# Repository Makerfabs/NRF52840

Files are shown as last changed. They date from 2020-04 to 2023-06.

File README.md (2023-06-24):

# MakePython nRF52840

```c++
/*
Version:		V2.0
Author:			UNKOWN
Create Date:	UNKOWN
Note:
	2020/7/24	v2.0: Rebuid readme,add pic. By Vincent
*/
```

[toc]

# Introduce

Python is one of the most widely used, simple and easy-to-learn programming languages around. CircuitPython is a lean implementation of the Python 3 programming language that has been pared down to run efficiently on microcontrollers.
MakePython nRF52840 is a powerful, generic BLE MCU module target to CircuitPython/MicroPython learners & developers. It is true “breadboard compatible”, with the very detailed pins explanation, it is easy to learn& use. The nRF52840 is ready to take advantage of the considerable performance improvements for Bluetooth Low Energy (LE) with the arrival of the Bluetooth 5 specification. Of greatest importance is the support for longer range (up to x4 compared to Bluetooth 4.x) and doubling of on-air data rate, up to 2 Mbs from 1 Mbs in Bluetooth 4.x
The MakePython nRF52840 leads out all pins of Nordic nRF52840, is programmed with CircuitPython by default, users can begin the CircuitPython developing as getting then on hand. It is also compatible with the Arduino making it easy to get started if the correct bootloader downloaded. There also the Makerfabs MakePython ESP8266, MakePython ESP32 and so on.

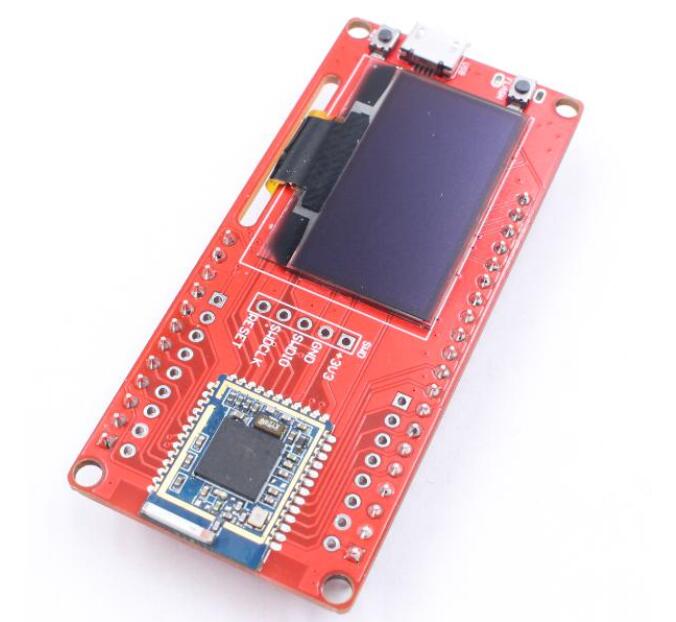
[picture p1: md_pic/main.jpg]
main


- You can get one from: [MakePython_nRF52840](https://www.makerfabs.com/makepython-nrf52840.html)

- Hardware and detailed instructions please visit Wiki page: [MakePython_nRF52840 Wiki](https://wiki.makerfabs.com/MaESP_nRF52840.html)

# Related Test

Visit the wiki for details.

- Display animation



- bluetooth communication



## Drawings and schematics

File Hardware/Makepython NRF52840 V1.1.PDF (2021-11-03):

# P0.06 P⁰.07

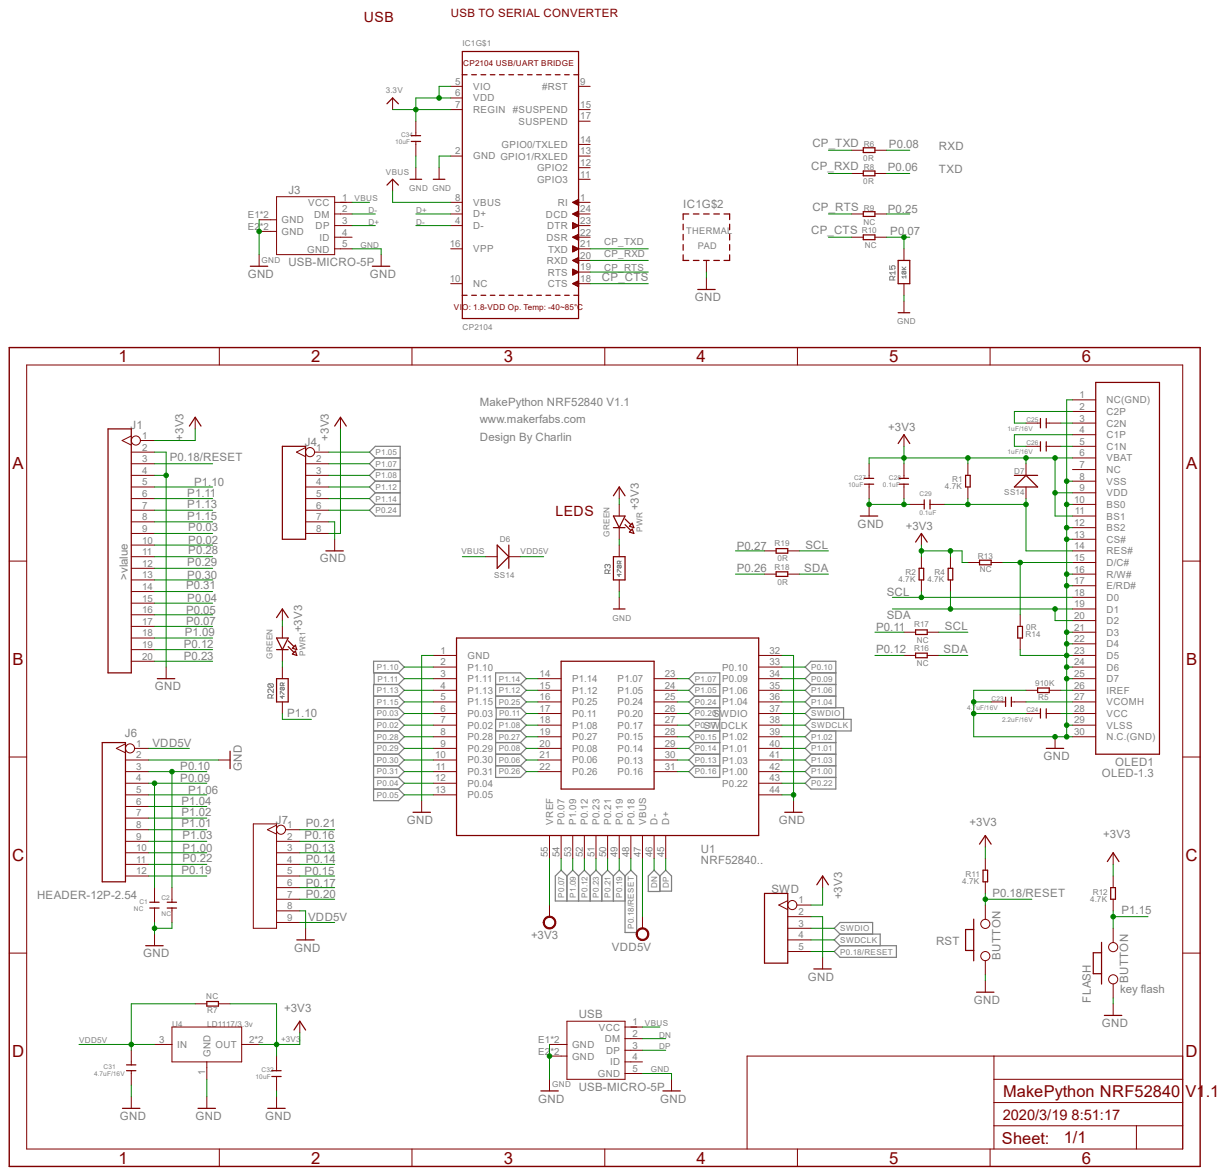
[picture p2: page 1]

VIO: 1.8-VDD Op. Temp: -40~85°C

NC 7 VSS 8 VDD 9

D1 19
D2 20

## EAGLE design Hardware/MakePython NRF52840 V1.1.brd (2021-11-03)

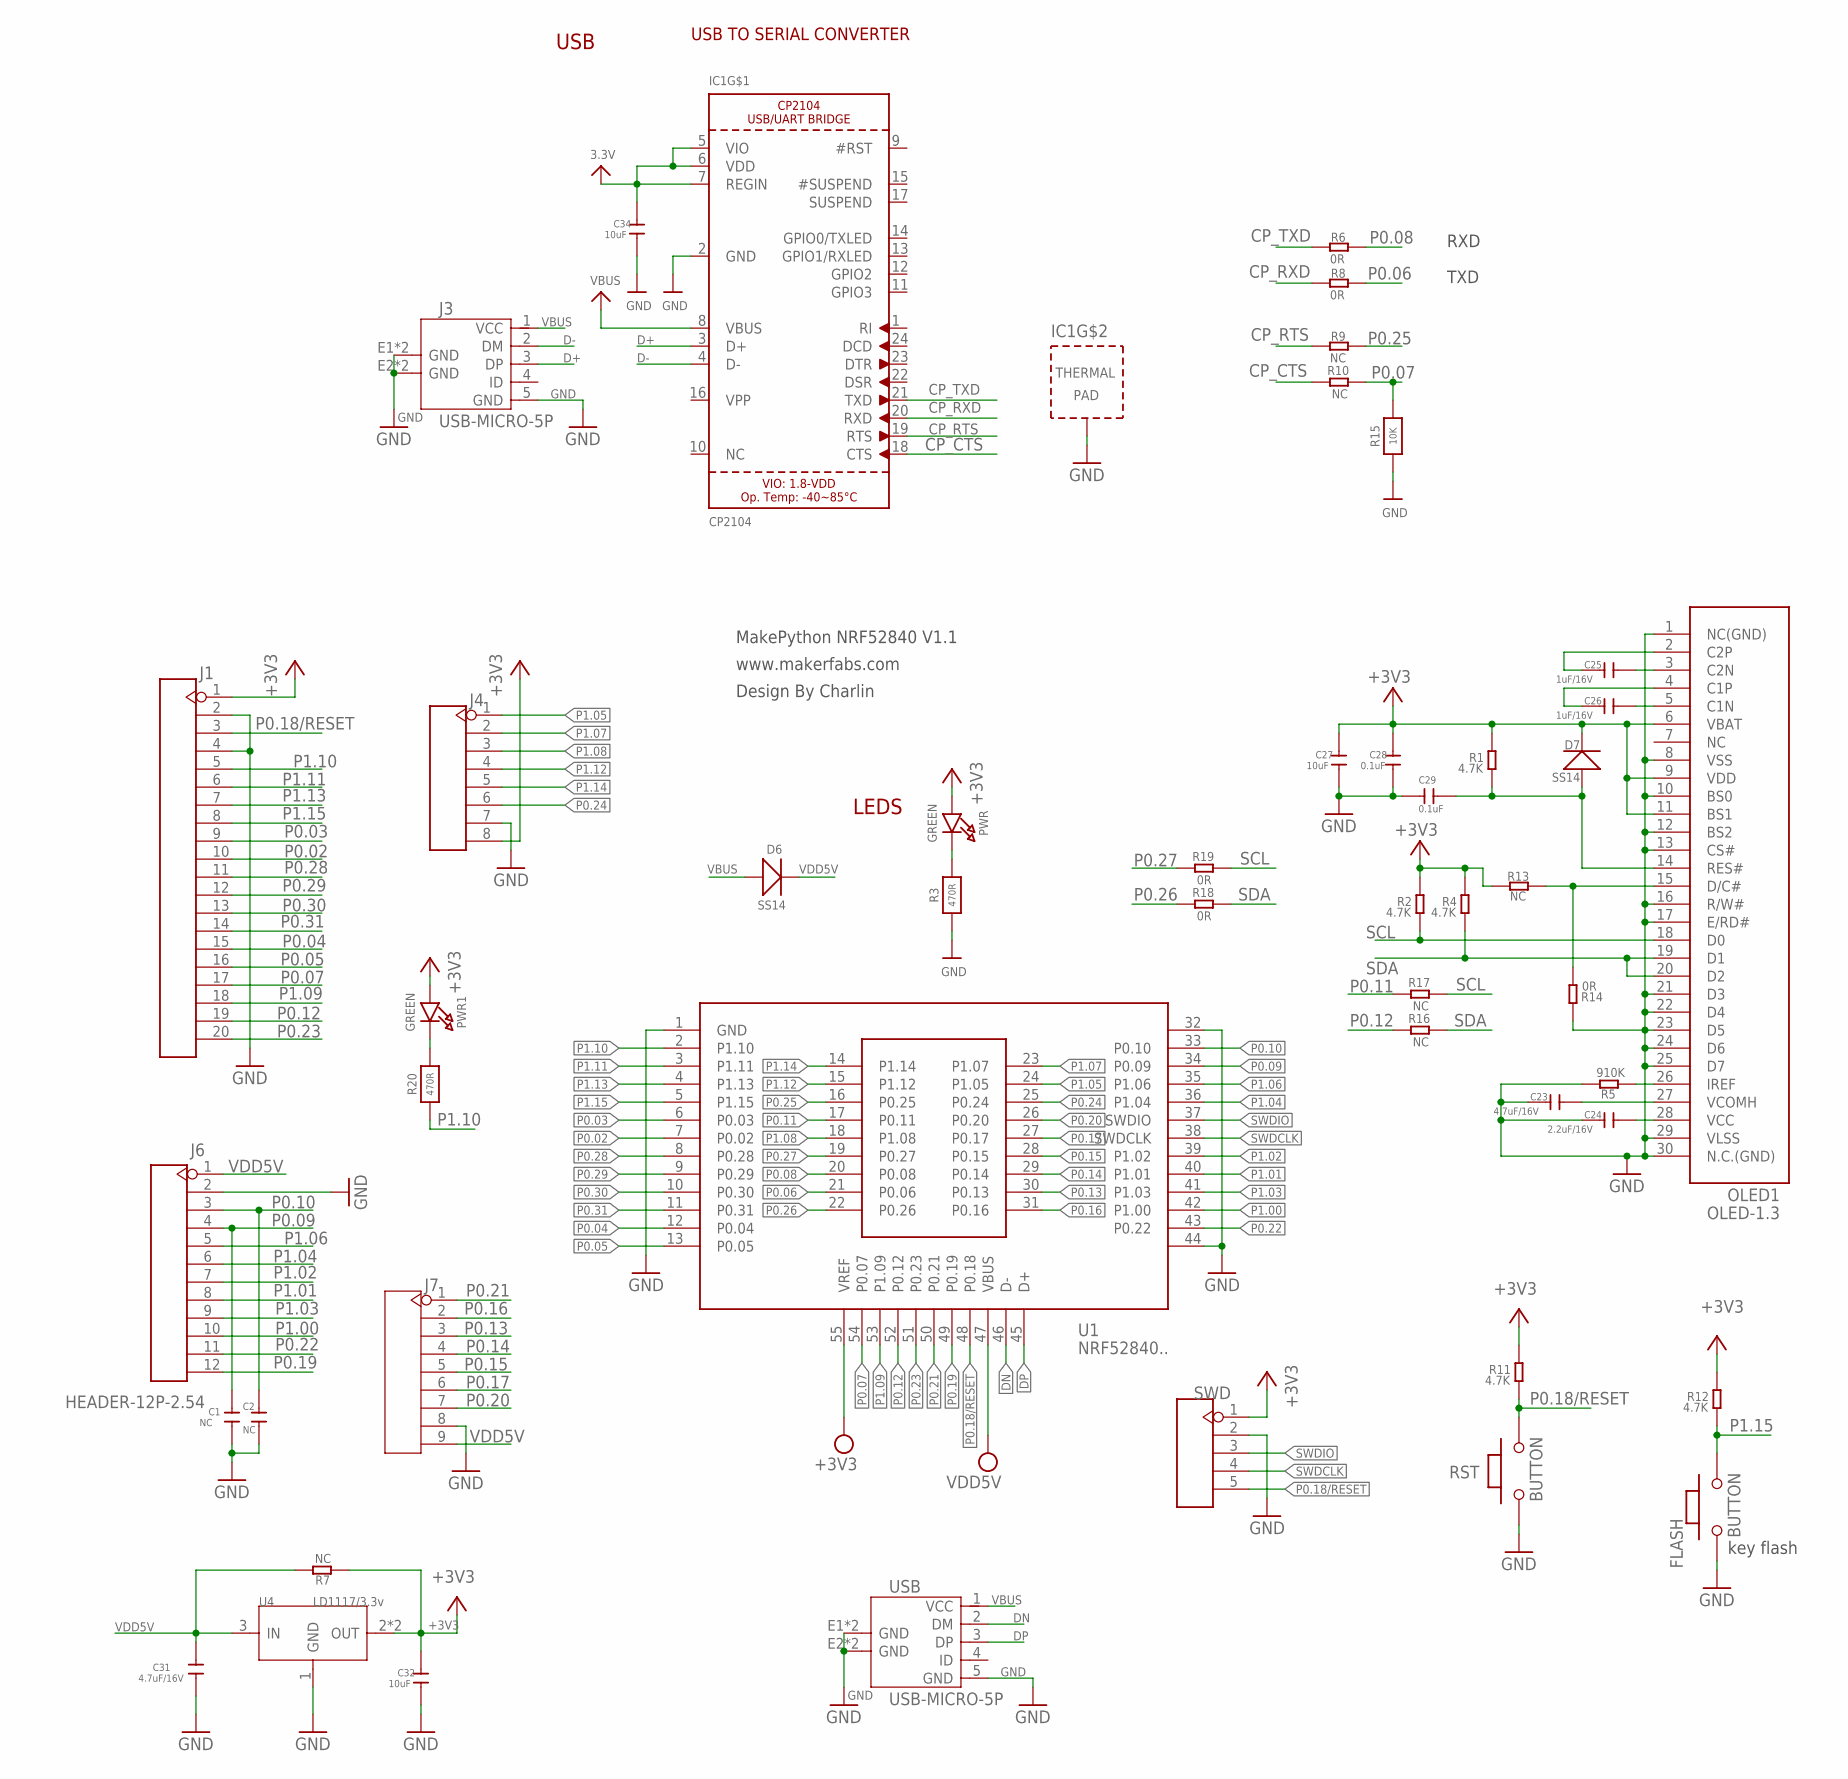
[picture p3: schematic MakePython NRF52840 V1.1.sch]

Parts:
C1, C2: NC; C0603
C23, C31: 4.7uF/16V; C0603
C24: 2.2uF/16V; C0603
C25, C26: 1uF/16V; C0603
C27, C32, C34: 10uF; C0603
C28, C29: 0.1uF; C0603
D6, D7: SS14; SOD323
FLASH: BUTTON; 157SW
IC1: CP2104; QFN24_4MM_SMSC
J1: HEADER-20P-2.54; 20P-2.54
J3: USB-MICRO-5P; MICRO-USB-5P
J4: HEADER-8P-2.54; 8P-2.54
J6: HEADER-12P-2.54; 12P-2.54
J7: HEADER-9P-2.54; 9P-2.54
OLED1: OLED-1.3
PWR, PWR1: GREEN; CHIPLED_0805_NOOUTLINE
R1, R2, R4, R11, R12: 4.7K; 0603
R3, R20: 470R; 0603-NO
R5: 910K; 0603
R6, R8, R14, R18, R19: 0R; 0603
R7, R9, R10, R13, R16, R17: NC; 0603
R15: 10K; 0603-NO
RST: BUTTON; 157SW
SWD: HEADER-5P-2.54; 5P-2.54
U1: NRF52840..
U4: LD1117/3.3v; SOT89
USB: USB-MICRO-5P; MICRO-USB-5P

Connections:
+3V3: C27.1, C28.1, C32.1, C34.1, D7.-, IC1.5 (VIO), IC1.6 (VDD), IC1.7 (REGIN), J1.1, J4.8, OLED1.6 (VBAT), OLED1.9 (VDD), OLED1.11 (BS1), PWR.A, PWR1.A, R1.2, R2.2, R4.2, R7.2, R11.2, R12.2, R13.2, SWD.1, U1.55 (VREF), U4.2 (OUT), U4.4 (OUT)
CP_CTS: IC1.18 (CTS), R10.2
CP_RTS: IC1.19 (RTS), R9.2
CP_RXD: IC1.20 (RXD), R8.2
CP_TXD: IC1.21 (TXD), R6.2
D+: IC1.3 (D+), J3.3 (DP)
D-: IC1.4 (D-), J3.2 (DM)
DN: U1.46 (D-), USB.2 (DM)
DP: U1.45 (D+), USB.3 (DP)
GND: C1.2, C2.2, C23.2, C24.2, C27.2, C28.2, C29.1, C31.2, C32.2, C34.2, FLASH.1, IC1.2 (GND), IC1.THERM (TP), J1.2, J1.4, J3.5 (GND), J3.E1 (GND), J3.E2 (GND), J3.P1 (GND), J3.P2 (GND), J4.7, J6.2, J7.8, OLED1.1 (NC(GND)), OLED1.8 (VSS), OLED1.10 (BS0), OLED1.12 (BS2), OLED1.13 (CS#), OLED1.16 (R/W#), OLED1.17 (E/RD#), OLED1.21 (D3), OLED1.22 (D4), OLED1.23 (D5), OLED1.24 (D6), OLED1.25 (D7), OLED1.29 (VLSS), OLED1.30 (N.C.(GND)), R3.1, R5.2, R14.2, R15.1, RST.1, SWD.2, U1.1 (GND), U1.32, U1.44, U4.1 (GND), USB.5 (GND), USB.E1 (GND), USB.E2 (GND), USB.P1 (GND), USB.P2 (GND)
unnamed: PWR1.C, R20.2
unnamed: OLED1.15 (D/C#), R13.1, R14.1
unnamed: PWR.C, R3.2
unnamed: C25.1, OLED1.3 (C2N)
unnamed: C25.2, OLED1.2 (C2P)
unnamed: C26.1, OLED1.5 (C1N)
unnamed: C26.2, OLED1.4 (C1P)
unnamed: C29.2, D7.+, OLED1.14 (RES#), R1.1
unnamed: OLED1.26 (IREF), R5.1
unnamed: C24.1, OLED1.28 (VCC)
unnamed: C23.1, OLED1.27 (VCOMH)
P0.02: J1.10, U1.7 (P0.02)
P0.03: J1.9, U1.6 (P0.03)
P0.04: J1.15, U1.12 (P0.04)
P0.05: J1.16, U1.13 (P0.05)
P0.06: R8.1, U1.21 (P0.06)
P0.07: J1.17, R10.1, R15.2, U1.54 (P0.07)
P0.08: R6.1, U1.20 (P0.08)
P0.09: C1.1, J6.4, U1.34 (P0.09)
P0.10: C2.1, J6.3, U1.33 (P0.10)
P0.11: R17.2, U1.17 (P0.11)
P0.12: J1.19, R16.2, U1.52 (P0.12)
P0.13: J7.3, U1.30 (P0.13)
P0.14: J7.4, U1.29 (P0.14)
P0.15: J7.5, U1.28 (P0.15)
P0.16: J7.2, U1.31 (P0.16)
P0.17: J7.6, U1.27 (P0.17)
P0.18/RESET: J1.3, R11.1, RST.2, SWD.5, U1.48 (P0.18)
P0.19: J6.12, U1.49 (P0.19)
P0.20: J7.7, U1.26 (P0.20)
P0.21: J7.1, U1.50 (P0.21)
P0.22: J6.11, U1.43 (P0.22)
P0.23: J1.20, U1.51 (P0.23)
P0.24: J4.6, U1.25 (P0.24)
P0.25: R9.1, U1.16 (P0.25)
P0.26: R18.2, U1.22 (P0.26)
P0.27: R19.2, U1.19 (P0.27)
P0.28: J1.11, U1.8 (P0.28)
P0.29: J1.12, U1.9 (P0.29)
P0.30: J1.13, U1.10 (P0.30)
P0.31: J1.14, U1.11 (P0.31)
P1.00: J6.10, U1.42 (P1.00)
P1.01: J6.8, U1.40 (P1.01)
P1.02: J6.7, U1.39 (P1.02)
P1.03: J6.9, U1.41 (P1.03)
P1.04: J6.6, U1.36 (P1.04)
P1.05: J4.1, U1.24 (P1.05)
P1.06: J6.5, U1.35 (P1.06)
P1.07: J4.2, U1.23 (P1.07)
P1.08: J4.3, U1.18 (P1.08)
P1.09: J1.18, U1.53 (P1.09)
P1.10: J1.5, R20.1, U1.2 (P1.10)
P1.11: J1.6, U1.3 (P1.11)
P1.12: J4.4, U1.15 (P1.12)
P1.13: J1.7, U1.4 (P1.13)
P1.14: J4.5, U1.14 (P1.14)
P1.15: FLASH.2, J1.8, R12.1, U1.5 (P1.15)
SCL: OLED1.18 (D0), R2.1, R17.1, R19.1
SDA: OLED1.19 (D1), OLED1.20 (D2), R4.1, R16.1, R18.1
SWDCLK: SWD.4, U1.38 (SWDCLK)
SWDIO: SWD.3, U1.37 (SWDIO)
VBUS: D6.+, IC1.8 (VBUS), J3.1 (VCC), USB.1 (VCC)
VDD5V: C31.1, D6.-, J6.1, J7.9, R7.1, U1.47 (VBUS), U4.3 (IN)

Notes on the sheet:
LEDS
key flash
USB
USB TO SERIAL CONVERTER
MakePython NRF52840 V1.1
www.makerfabs.com
Design By Charlin
RXD
TXD

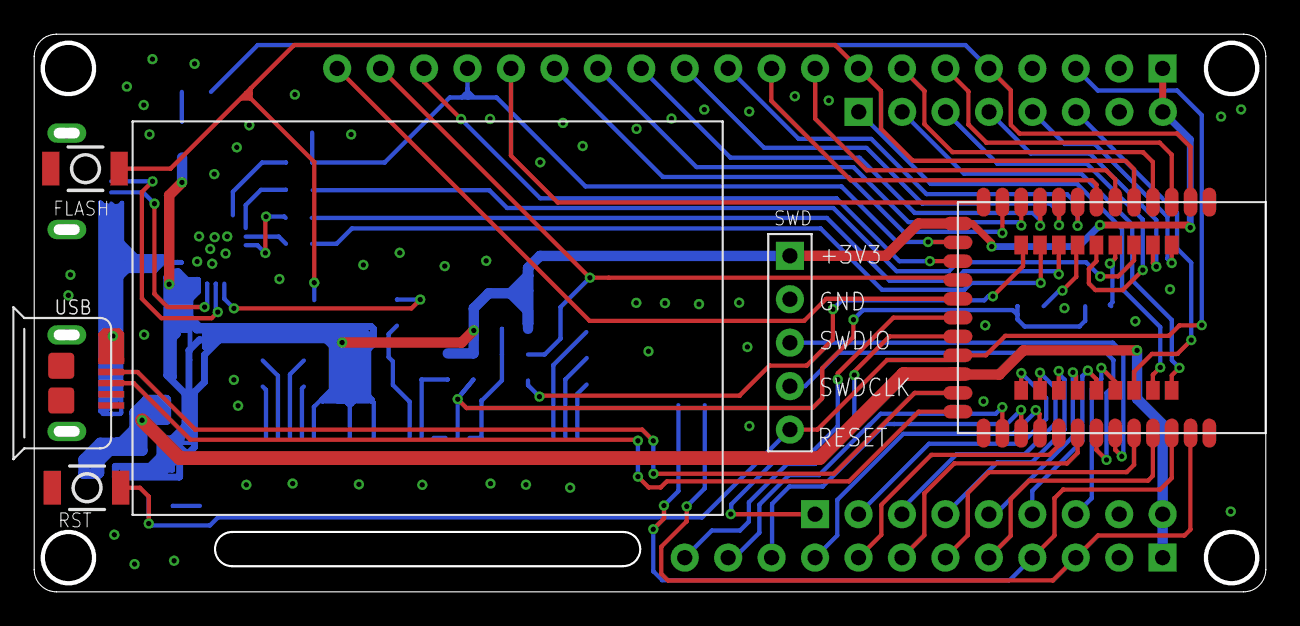
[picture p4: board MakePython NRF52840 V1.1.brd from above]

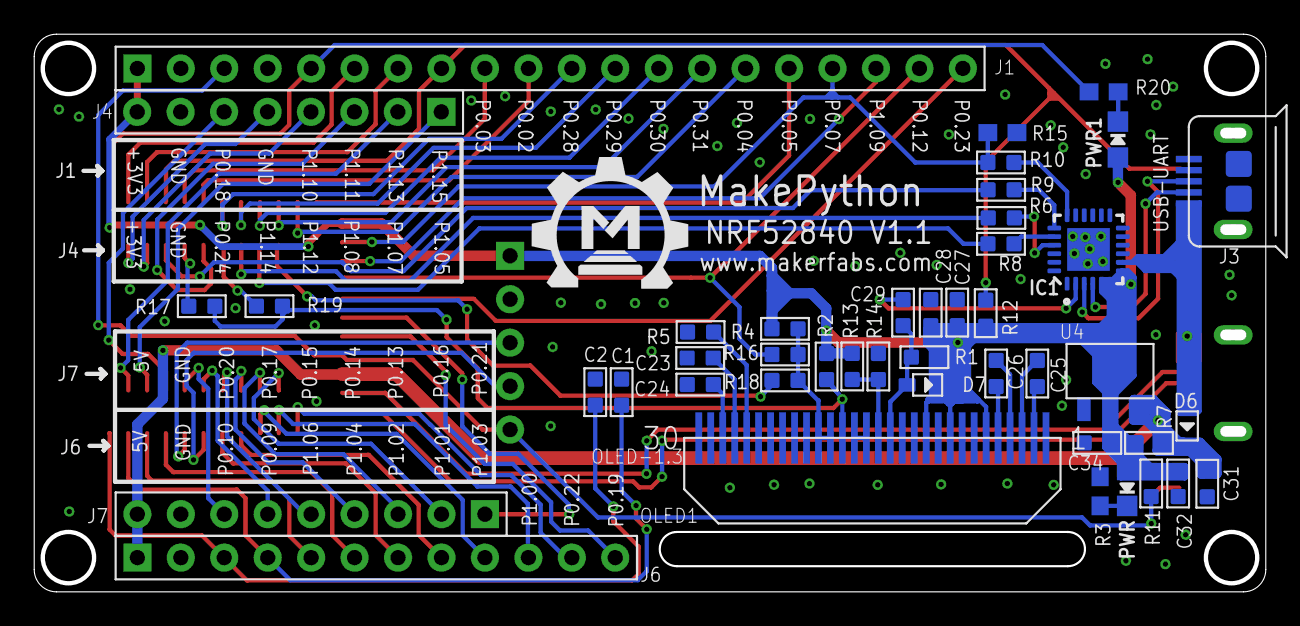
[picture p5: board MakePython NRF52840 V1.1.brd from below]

Board: 2 copper layers, 72.0 x 32.6 mm, 50 parts (44 on the bottom side), 73 nets.

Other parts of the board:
U$1: MAKERFABS_0.3

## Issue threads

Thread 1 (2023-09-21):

LED pin is wrong

bradjc, 2023-09-21:
The "PWR1" LED is connected to pin P1.11.

As far as I can tell the issue is that the nRF52840 module part in the hardware files has pins P1.10 and P1.11 swapped.

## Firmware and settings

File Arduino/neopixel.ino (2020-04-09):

/*********************************************************************
 This is an example for our nRF52 based Bluefruit LE modules

 Pick one up today in the adafruit shop!

 Adafruit invests time and resources providing this open source code,
 please support Adafruit and open-source hardware by purchasing
 products from Adafruit!

 MIT license, check LICENSE for more information
 All text above, and the splash screen below must be included in
 any redistribution
*********************************************************************/

// This sketch is intended to be used with the NeoPixel control
// surface in Adafruit's Bluefruit LE Connect mobile application.
//
// - Compile and flash this sketch to the nRF52 Feather
// - Open the Bluefruit LE Connect app
// - Switch to the NeoPixel utility
// - Click the 'connect' button to establish a connection and
//   send the meta-data about the pixel layout
// - Use the NeoPixel utility to update the pixels on your device

/* NOTE: This sketch required at least version 1.1.0 of Adafruit_Neopixel !!! */

#include <Arduino.h>
#include <Adafruit_NeoPixel.h>
#include <bluefruit.h>

#define NEOPIXEL_VERSION_STRING "Neopixel v2.0"
#define PIN                     30   /* Pin used to drive the NeoPixels */

#define MAXCOMPONENTS  4
uint8_t *pixelBuffer = NULL;
uint8_t width = 0;
uint8_t height = 0;
uint8_t stride;
uint8_t componentsValue;
bool is400Hz;
uint8_t components = 3;     // only 3 and 4 are valid values

Adafruit_NeoPixel neopixel = Adafruit_NeoPixel();

// BLE Service
BLEDfu  bledfu;
BLEDis  bledis;
BLEUart bleuart;

void setup()
{
  Serial.begin(115200);
  while ( !Serial ) delay(10);   // for nrf52840 with native usb

  Serial.println("Adafruit Bluefruit Neopixel Test");
  Serial.println("--------------------------------");

  Serial.println();
  Serial.println("Please connect using the Bluefruit Connect LE application");
  
  // Config Neopixels
  neopixel.begin();

  // Init Bluefruit
  Bluefruit.begin();
  Bluefruit.setTxPower(4);    // Check bluefruit.h for supported values
  Bluefruit.setName("Bluefruit52");
  Bluefruit.Periph.setConnectCallback(connect_callback);

  // To be consistent OTA DFU should be added first if it exists
  bledfu.begin();

  // Configure and Start Device Information Service
  bledis.setManufacturer("Adafruit Industries");
  bledis.setModel("Bluefruit Feather52");
  bledis.begin();  

  // Configure and start BLE UART service
  bleuart.begin();

  // Set up and start advertising
  startAdv();
}

void startAdv(void)
{  
  // Advertising packet
  Bluefruit.Advertising.addFlags(BLE_GAP_ADV_FLAGS_LE_ONLY_GENERAL_DISC_MODE);
  Bluefruit.Advertising.addTxPower();
  
  // Include bleuart 128-bit uuid
  Bluefruit.Advertising.addService(bleuart);

  // Secondary Scan Response packet (optional)
  // Since there is no room for 'Name' in Advertising packet
  Bluefruit.ScanResponse.addName();
  
  /* Start Advertising
   * - Enable auto advertising if disconnected
   * - Interval:  fast mode = 20 ms, slow mode = 152.5 ms
   * - Timeout for fast mode is 30 seconds
   * - Start(timeout) with timeout = 0 will advertise forever (until connected)
   * 
   * For recommended advertising interval
   * https://developer.apple.com/library/content/qa/qa1931/_index.html   
   */
  Bluefruit.Advertising.restartOnDisconnect(true);
  Bluefruit.Advertising.setInterval(32, 244);    // in unit of 0.625 ms
  Bluefruit.Advertising.setFastTimeout(30);      // number of seconds in fast mode
  Bluefruit.Advertising.start(0);                // 0 = Don't stop advertising after n seconds  
}

void connect_callback(uint16_t conn_handle)
{
  // Get the reference to current connection
  BLEConnection* connection = Bluefruit.Connection(conn_handle);

  char central_name[32] = { 0 };
  connection->getPeerName(central_name, sizeof(central_name));

  Serial.print("Connected to ");
  Serial.println(central_name);

  Serial.println("Please select the 'Neopixels' tab, click 'Connect' and have fun");
}

void loop()
{
  // Echo received data
  if ( Bluefruit.connected() && bleuart.notifyEnabled() )
  {
    int command = bleuart.read();

    switch (command) {
      case 'V': {   // Get Version
          commandVersion();
          break;
        }
  
      case 'S': {   // Setup dimensions, components, stride...
          commandSetup();
          break;
       }

      case 'C': {   // Clear with color
          commandClearColor();
          break;
      }

      case 'B': {   // Set Brightness
          commandSetBrightness();
          break;
      }
            
      case 'P': {   // Set Pixel
          commandSetPixel();
          break;
      }
  
      case 'I': {   // Receive new image
          commandImage();
          break;
       }

    }
  }
}

void swapBuffers()
{
  uint8_t *base_addr = pixelBuffer;
  int pixelIndex = 0;
  for (int j = 0; j < height; j++)
  {
    for (int i = 0; i < width; i++) {
      if (components == 3) {
        neopixel.setPixelColor(pixelIndex, neopixel.Color(*base_addr, *(base_addr+1), *(base_addr+2)));
      }
      else {
        neopixel.setPixelColor(pixelIndex, neopixel.Color(*base_addr, *(base_addr+1), *(base_addr+2), *(base_addr+3) ));
      }
      base_addr+=components;
      pixelIndex++;
    }
    pixelIndex += stride - width;   // Move pixelIndex to the next row (take into account the stride)
  }
  neopixel.show();

}

void commandVersion() {
  Serial.println(F("Command: Version check"));
  sendResponse(NEOPIXEL_VERSION_STRING);
}

void commandSetup() {
  Serial.println(F("Command: Setup"));

  width = bleuart.read();
  height = bleuart.read();
  stride = bleuart.read();
  componentsValue = bleuart.read();
  is400Hz = bleuart.read();

  neoPixelType pixelType;
  pixelType = componentsValue + (is400Hz ? NEO_KHZ400 : NEO_KHZ800);

  components = (componentsValue == NEO_RGB || componentsValue == NEO_RBG || componentsValue == NEO_GRB || componentsValue == NEO_GBR || componentsValue == NEO_BRG || componentsValue == NEO_BGR) ? 3:4;
  
  Serial.printf("\tsize: %dx%d\n", width, height);
  Serial.printf("\tstride: %d\n", stride);
  Serial.printf("\tpixelType %d\n", pixelType);
  Serial.printf("\tcomponents: %d\n", components);

  if (pixelBuffer != NULL) {
      delete[] pixelBuffer;
  }

  uint32_t size = width*height;
  pixelBuffer = new uint8_t[size*components];
  neopixel.updateLength(size);
  neopixel.updateType(pixelType);
  neopixel.setPin(PIN);

  // Done
  sendResponse("OK");
}

void commandSetBrightness() {
  Serial.println(F("Command: SetBrightness"));

   // Read value
  uint8_t brightness = bleuart.read();

  // Set brightness
  neopixel.setBrightness(brightness);

  // Refresh pixels
  swapBuffers();

  // Done
  sendResponse("OK");
}

void commandClearColor() {
  Serial.println(F("Command: ClearColor"));

  // Read color
  uint8_t color[MAXCOMPONENTS];
  for (int j = 0; j < components;) {
    if (bleuart.available()) {
      color[j] = bleuart.read();
      j++;
    }
  }

  // Set all leds to color
  int size = width * height;
  uint8_t *base_addr = pixelBuffer;
  for (int i = 0; i < size; i++) {
    for (int j = 0; j < components; j++) {
      *base_addr = color[j];
      base_addr++;
    }
  }

  // Swap buffers
  Serial.println(F("ClearColor completed"));
  swapBuffers();


  if (components == 3) {
    Serial.printf("\tclear (%d, %d, %d)\n", color[0], color[1], color[2] );
  }
  else {
    Serial.printf("\tclear (%d, %d, %d, %d)\n", color[0], color[1], color[2], color[3] );
  }
  
  // Done
  sendResponse("OK");
}

void commandSetPixel() {
  Serial.println(F("Command: SetPixel"));

  // Read position
  uint8_t x = bleuart.read();
  uint8_t y = bleuart.read();

  // Read colors
  uint32_t pixelOffset = y*width+x;
  uint32_t pixelDataOffset = pixelOffset*components;
  uint8_t *base_addr = pixelBuffer+pixelDataOffset;
  for (int j = 0; j < components;) {
    if (bleuart.available()) {
      *base_addr = bleuart.read();
      base_addr++;
      j++;
    }
  }

  // Set colors
  uint32_t neopixelIndex = y*stride+x;
  uint8_t *pixelBufferPointer = pixelBuffer + pixelDataOffset;
  uint32_t color;
  if (components == 3) {
    color = neopixel.Color( *pixelBufferPointer, *(pixelBufferPointer+1), *(pixelBufferPointer+2) );
    Serial.printf("\tcolor (%d, %d, %d)\n",*pixelBufferPointer, *(pixelBufferPointer+1), *(pixelBufferPointer+2) );
  }
  else {
    color = neopixel.Color( *pixelBufferPointer, *(pixelBufferPointer+1), *(pixelBufferPointer+2), *(pixelBufferPointer+3) );
    Serial.printf("\tcolor (%d, %d, %d, %d)\n", *pixelBufferPointer, *(pixelBufferPointer+1), *(pixelBufferPointer+2), *(pixelBufferPointer+3) );    
  }
  neopixel.setPixelColor(neopixelIndex, color);
  neopixel.show();

  // Done
  sendResponse("OK");
}

void commandImage() {
  Serial.printf("Command: Image %dx%d, %d, %d\n", width, height, components, stride);
  
  // Receive new pixel buffer
  int size = width * height;
  uint8_t *base_addr = pixelBuffer;
  for (int i = 0; i < size; i++) {
    for (int j = 0; j < components;) {
      if (bleuart.available()) {
        *base_addr = bleuart.read();
        base_addr++;
        j++;
      }
    }

/*
    if (components == 3) {
      uint32_t index = i*components;
      Serial.printf("\tp%d (%d, %d, %d)\n", i, pixelBuffer[index], pixelBuffer[index+1], pixelBuffer[index+2] );
    }
    */
  }

  // Swap buffers
  Serial.println(F("Image received"));
  swapBuffers();

  // Done
  sendResponse("OK");
}

void sendResponse(char const *response) {
    Serial.printf("Send Response: %s\n", response);
    bleuart.write(response, strlen(response)*sizeof(char));
}

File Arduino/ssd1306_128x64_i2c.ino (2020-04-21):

/**************************************************************************
 This is an example for our Monochrome OLEDs based on SSD1306 drivers

 Pick one up today in the adafruit shop!
 ------> http://www.adafruit.com/category/63_98

 This example is for a 128x32 pixel display using I2C to communicate
 3 pins are required to interface (two I2C and one reset).

 Adafruit invests time and resources providing this open
 source code, please support Adafruit and open-source
 hardware by purchasing products from Adafruit!

 Written by Limor Fried/Ladyada for Adafruit Industries,
 with contributions from the open source community.
 BSD license, check license.txt for more information
 All text above, and the splash screen below must be
 included in any redistribution.
 **************************************************************************/

#include <SPI.h>
#include <Wire.h>
#include <Adafruit_GFX.h>
#include <Adafruit_SSD1306.h>

#define SCREEN_WIDTH 128 // OLED display width, in pixels
#define SCREEN_HEIGHT 64 // OLED display height, in pixels

// Declaration for an SSD1306 display connected to I2C (SDA, SCL pins)
#define OLED_RESET     -1 // Reset pin # (or -1 if sharing Arduino reset pin)
Adafruit_SSD1306 display(SCREEN_WIDTH, SCREEN_HEIGHT, &Wire, OLED_RESET);

#define NUMFLAKES     10 // Number of snowflakes in the animation example

#define LOGO_HEIGHT   16
#define LOGO_WIDTH    16
/**
static const unsigned char PROGMEM logo_bmp[] =
{ B00000000, B11000000,
  B00000001, B11000000,
  B00000001, B11000000,
  B00000011, B11100000,
  B11110011, B11100000,
  B11111110, B11111000,
  B01111110, B11111111,
  B00110011, B10011111,
  B00011111, B11111100,
  B00001101, B01110000,
  B00011011, B10100000,
  B00111111, B11100000,
  B00111111, B11110000,
  B01111100, B11110000,
  B01110000, B01110000,
  B00000000, B00110000 };
**/
/**
static const unsigned char PROGMEM logo_bmp[] =
{ B11111111,0xFF,
0x83,0xC1,
0xBF,0xFD,
0xFE,0x7F,
0xBE,0x7D,
0xF7,0xED,
0xF7,0xEF,
0xE7,0xEF,
0xE6,0x6F,
0xF3,0xCF,
0xBF,0xFD,
0xBF,0xFD,
0xF8,0x1F,
0xFC,0x7D,
0xFF,0xFF,
0xFF,0xFF };
***/
static const unsigned char PROGMEM logo_bmp[] =
{ B11111111,B11111111,
B10000011,B11000001,
B10111111,B11111101,
B11111110,B01111111,
B10111110,B01111101,
B11110111,B11101101,
B11110111,B11101111,
B11100111,B11101111,
B11100110,B01101111,
B11110011,B11001111,
B10111111,B11111101,
B10111111,B11111101,
B11111000,B00011111,
B11111100,B01111101,
B11111111,B11111111,
B11111111,B11111111 };

//Makerfabs logo
static const unsigned char PROGMEM logo_bmp1[] =
{0x00,0x00,0x00,0x00,0x00,0x00,0x03,0xFC,0x00,0x00,0x00,0x00,0x00,0x00,0x00,0x00,
0x00,0x00,0x00,0x00,0x00,0x00,0x03,0xFC,0x00,0x00,0x00,0x00,0x00,0x00,0x00,0x00,
0x00,0x00,0x00,0x00,0x00,0x00,0x07,0xFE,0x00,0x00,0x00,0x00,0x00,0x00,0x00,0x00,
0x00,0x00,0x00,0x00,0x00,0x00,0x07,0xFE,0x00,0x00,0x00,0x00,0x00,0x00,0x00,0x00,
0x00,0x00,0x00,0x00,0x00,0x00,0x0F,0xFE,0x00,0x00,0x00,0x00,0x00,0x00,0x00,0x00,
0x00,0x00,0x00,0x00,0x00,0x80,0x7F,0xFF,0xE0,0x10,0x00,0x00,0x00,0x00,0x00,0x00,
0x00,0x00,0x00,0x00,0x01,0xE1,0xFF,0xFF,0xF8,0x78,0x00,0x00,0x00,0x00,0x00,0x00,
0x00,0x00,0x00,0x00,0x03,0xFF,0xFF,0xFF,0xFF,0xFC,0x00,0x00,0x00,0x00,0x00,0x00,
0x00,0x00,0x00,0x00,0x07,0xFF,0xF8,0x01,0xFF,0xFF,0x00,0x00,0x00,0x00,0x00,0x00,
0x00,0x00,0x00,0x00,0x0F,0xFF,0xC0,0x00,0x3F,0xFF,0x80,0x00,0x00,0x00,0x00,0x00,
0x00,0x00,0x00,0x00,0x1F,0xFF,0x00,0x00,0x0F,0xFF,0x80,0x00,0x00,0x00,0x00,0x00,
0x00,0x00,0x00,0x00,0x0F,0xFC,0x00,0x00,0x07,0xFF,0x00,0x00,0x00,0x00,0x00,0x00,
0x00,0x00,0x00,0x00,0x07,0xF8,0x00,0x00,0x01,0xFE,0x00,0x00,0x00,0x00,0x00,0x00,
0x00,0x00,0x00,0x00,0x07,0xF0,0x00,0x00,0x00,0xFE,0x00,0x00,0x00,0x00,0x00,0x00,
0x00,0x00,0x00,0x00,0x07,0xE1,0xF0,0x01,0xF8,0x7C,0x00,0x00,0x00,0x00,0x00,0x00,
0x00,0x00,0x00,0x00,0x07,0xC1,0xF8,0x03,0xF8,0x3E,0x00,0x00,0x00,0x00,0x00,0x00,
0x00,0x00,0x00,0x00,0x0F,0x81,0xFC,0x07,0xF8,0x3E,0x00,0x00,0x00,0x00,0x00,0x00,
0x00,0x00,0x00,0x00,0x0F,0x81,0xFE,0x0F,0xF8,0x1F,0x00,0x00,0x00,0x00,0x00,0x00,
0x00,0x00,0x00,0x00,0x0F,0x01,0xFF,0x1F,0xF8,0x1F,0x00,0x00,0x00,0x00,0x00,0x00,
0x00,0x00,0x00,0x00,0x1F,0x01,0xF7,0xBF,0xF8,0x0F,0x80,0x00,0x00,0x00,0x00,0x00,
0x00,0x00,0x00,0x00,0x1F,0x01,0xF3,0x7E,0xF8,0x0F,0x80,0x00,0x00,0x00,0x00,0x00,
0x00,0x00,0x00,0x00,0x7E,0x01,0xF0,0xFC,0xF8,0x0F,0xF8,0x00,0x00,0x00,0x00,0x00,
0x00,0x00,0x00,0x03,0xFE,0x01,0xF0,0xF8,0xF8,0x07,0xFE,0x00,0x00,0x00,0x00,0x00,
0x00,0x00,0x00,0x03,0xFE,0x01,0xF0,0x70,0xF8,0x07,0xFE,0x00,0x00,0x00,0x00,0x00,
0x00,0x00,0x00,0x03,0xFE,0x01,0xF0,0x20,0xF8,0x07,0xFE,0x00,0x00,0x00,0x00,0x00,
0x00,0x00,0x00,0x03,0xFE,0x01,0xF0,0x00,0xF8,0x07,0xFE,0x00,0x00,0x00,0x00,0x00,
0x00,0x00,0x00,0x03,0xFE,0x01,0xF0,0x00,0xF8,0x07,0xFE,0x00,0x00,0x00,0x00,0x00,
0x00,0x00,0x00,0x03,0xFE,0x01,0xF0,0x00,0xF8,0x07,0xFE,0x00,0x00,0x00,0x00,0x00,
0x00,0x00,0x00,0x03,0xFF,0x00,0x00,0x00,0x00,0x0F,0xFE,0x00,0x00,0x00,0x00,0x00,
0x00,0x00,0x00,0x01,0xFF,0x00,0x0F,0xFF,0x00,0x0F,0xF8,0x00,0x00,0x00,0x00,0x00,
0x00,0x00,0x00,0x00,0x1F,0x00,0x1F,0xFF,0xC0,0x0F,0x00,0x00,0x00,0x00,0x00,0x00,
0x00,0x00,0x00,0x00,0x0F,0x80,0x00,0x00,0x00,0x1F,0x00,0x00,0x00,0x00,0x00,0x00,
0x00,0x00,0x00,0x00,0x0F,0x80,0xFF,0xFF,0xF0,0x1F,0x00,0x00,0x00,0x00,0x00,0x00,
0x00,0x00,0x00,0x00,0x07,0xC1,0xFF,0xFF,0xF8,0x3E,0x00,0x00,0x00,0x00,0x00,0x00,
0x00,0x00,0x00,0x00,0x07,0xE3,0xFF,0xFF,0xFC,0x7E,0x00,0x00,0x00,0x00,0x00,0x00,
0x00,0x00,0x00,0x00,0x03,0xF3,0xFF,0xFF,0xFC,0xFC,0x00,0x00,0x00,0x00,0x00,0x00,
0x00,0x00,0x00,0x00,0x01,0xFB,0xFF,0xFF,0xFD,0xFC,0x00,0x00,0x00,0x00,0x00,0x00,
0x00,0x00,0x00,0x00,0x03,0xFC,0x00,0x00,0x03,0xFE,0x00,0x00,0x00,0x00,0x00,0x00,
0x00,0x00,0x00,0x00,0x07,0xFC,0x00,0x00,0x03,0xFF,0x00,0x00,0x00,0x00,0x00,0x00,
0x00,0x00,0x00,0x00,0x0F,0xFC,0x00,0x00,0x03,0xFF,0x00,0x00,0x00,0x00,0x00,0x00,
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

void setup() {
  Serial.begin(115200);
  Serial.println(F("SSD1306 init"));
  Serial.println("Hello, Makerfabs!");
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

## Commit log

2020-04-29 Create Arduino
2021-11-03 add hardware
    [MakePython NRF52840 V1.1.brd, MakePython NRF52840 V1.1.sch]

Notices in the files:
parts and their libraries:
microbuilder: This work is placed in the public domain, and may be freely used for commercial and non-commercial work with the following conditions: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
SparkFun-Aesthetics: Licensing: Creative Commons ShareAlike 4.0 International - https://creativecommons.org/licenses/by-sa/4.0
